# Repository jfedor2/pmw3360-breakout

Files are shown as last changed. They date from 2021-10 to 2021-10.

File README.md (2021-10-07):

# PMW3360 breakout board

This repository contains PCB design files for a breakout board for the PMW3360 optical mouse sensor.

The board doesn't do any level shifting so it only works with 3.3V logic.

The dimensions of the board are 22x34mm and the mounting holes are for M2 screws.

The files in the [fabrication](fabrication) folder can be used to order this board from JLCPCB with SMT assembly. The board you get includes everything except the actual sensor. If some of the specific components are out of stock, try to find an equivalent with the same package and parameters.

The sensor chip should be soldered on the top side (the side where all the other components are). The dot marks pin 1. The optic goes on the bottom side.

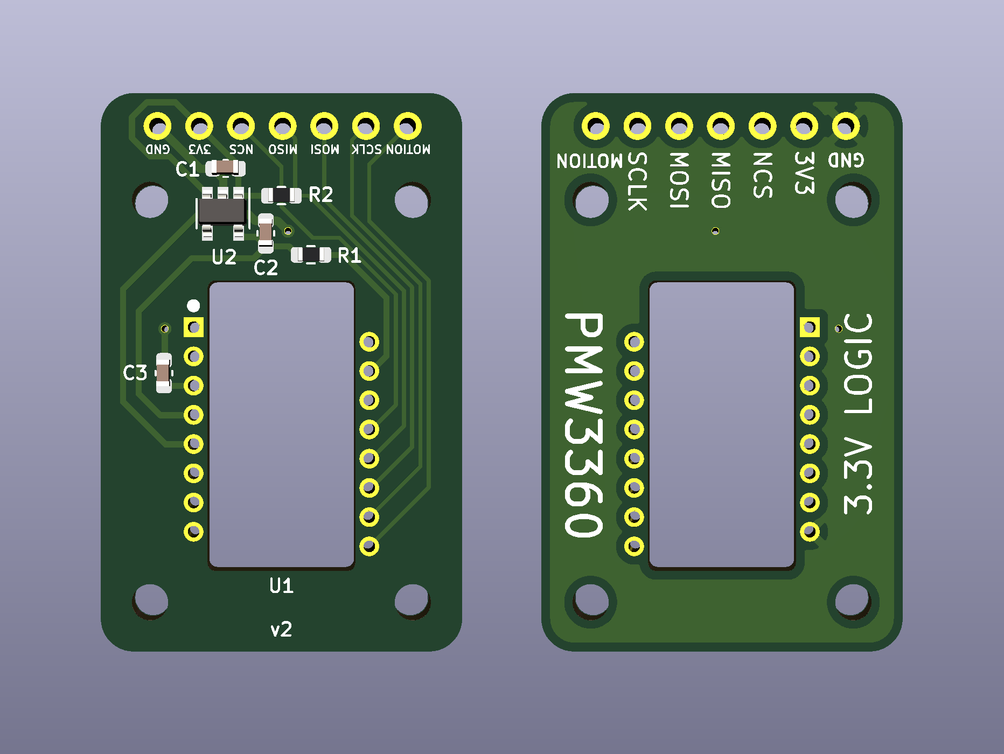
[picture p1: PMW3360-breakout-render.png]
a render of the PCB


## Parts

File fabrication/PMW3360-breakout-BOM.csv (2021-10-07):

Comment | Designator | Footprint | LCSC
0.1u | C1 | Capacitor_SMD:C_0603_1608Metric | C14663
1u | C2 | Capacitor_SMD:C_0603_1608Metric | C15849
4.7u | C3 | Capacitor_SMD:C_0603_1608Metric | C19666
Conn_01x07 | J1 | Connector_PinHeader_2.54mm:PinHeader_1x07_P2.54mm_Vertical
39 | R1 | Resistor_SMD:R_0603_1608Metric | C137733
10k | R2 | Resistor_SMD:R_0603_1608Metric | C25804
PMW3360 | U1 | PMW3360:PMW3360
TCR2EF19 | U2 | Package_TO_SOT_SMD:SOT-23-5 | C146366

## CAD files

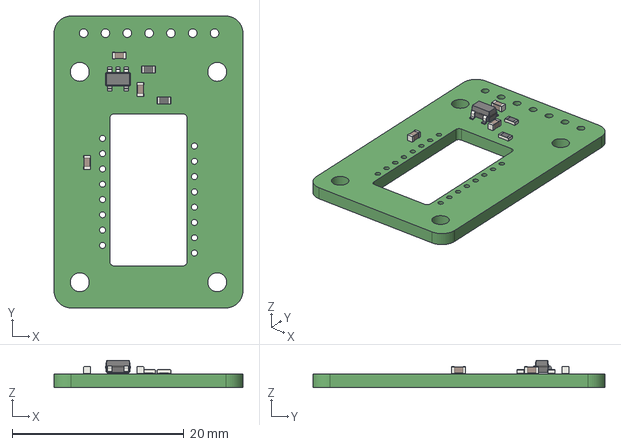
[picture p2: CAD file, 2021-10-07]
PMW3360-breakout.step
22.0 x 34.0 x 3.20 mm

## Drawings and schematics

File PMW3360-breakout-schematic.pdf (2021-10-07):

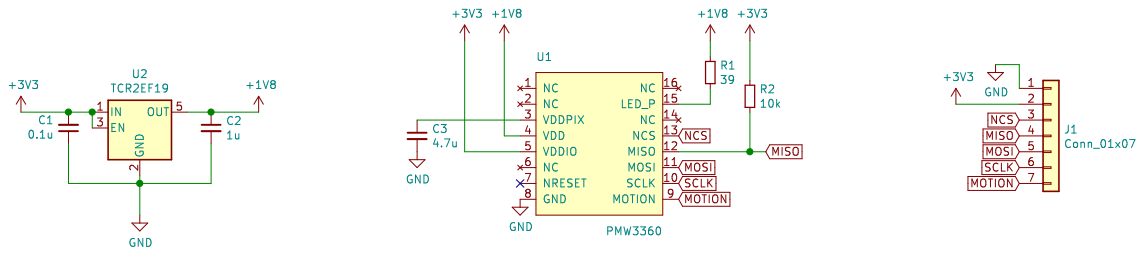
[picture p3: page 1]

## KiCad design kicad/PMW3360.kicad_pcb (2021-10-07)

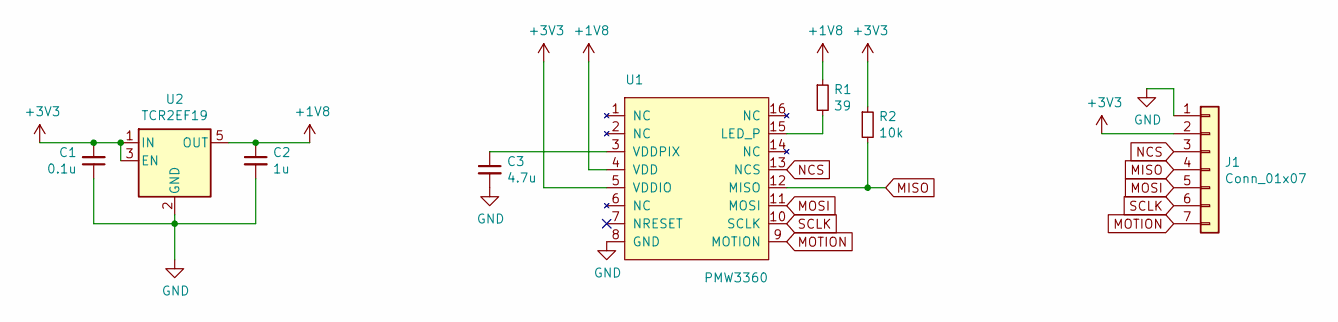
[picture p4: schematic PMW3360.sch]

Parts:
C1: 0.1u; C_0603_1608Metric; LCSC C14663
C2: 1u; C_0603_1608Metric; LCSC C15849
C3: 4.7u; C_0603_1608Metric; LCSC C19666
J1: Conn_01x07; PinHeader_1x07_P2.54mm_Vertical
R1: 39; R_0603_1608Metric; LCSC C137733
R2: 10k; R_0603_1608Metric; LCSC C25804
U1: PMW3360
U2: TCR2EF19; SOT-23-5; LCSC C146366

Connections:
+1V8: C2.1, R1.1, U1.4 (VDD), U2.5 (OUT)
+3V3: C1.2, J1.2, R2.1, U1.5 (VDDIO), U2.1 (IN), U2.3 (EN)
GND: C1.1, C2.2, C3.2, J1.1, U1.8 (GND), U2.2 (GND)
MISO: J1.4, R2.2, U1.12 (MISO)
MOSI: J1.5, U1.11 (MOSI)
MOTION: J1.7, U1.9 (MOTION)
NCS: J1.3, U1.13 (NCS)
unnamed: C3.1, U1.3 (VDDPIX)
unnamed: R1.2, U1.15 (LED_P)
SCLK: J1.6, U1.10 (SCLK)

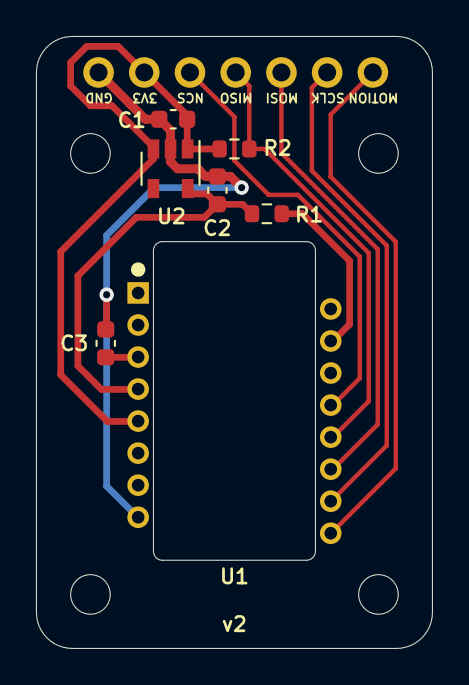
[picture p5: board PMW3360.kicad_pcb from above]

Board: 2 copper layers, 22.0 x 34.0 mm, 8 parts (0 on the bottom side), 10 nets.
